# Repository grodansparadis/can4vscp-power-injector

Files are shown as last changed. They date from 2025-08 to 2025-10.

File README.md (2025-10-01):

# Power injector module for CAN4VSCP

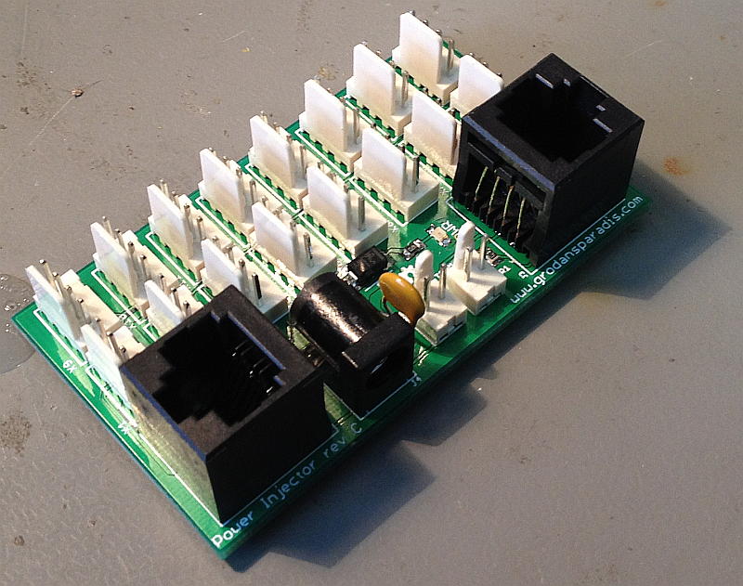
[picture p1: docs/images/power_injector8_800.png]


# Abstract

With the power injector you can power the CAN4VSCP bus and also power up to 16 CAN4VSCP modules using the inter module connector. This is a perfect companion board to use when you need to connect a number of CAN4VSCP boards in a cabinet and then connect them to the world.

It have two 120 ohm terminations that can be activated if needed and two RJ-45 connectors for easy connection.

The module has a resettable fuse that allow a maximum of 500 mA for all modules connected to the board. The fuse will trip at about 800 mA. This can be a good safety precaution for wired networks. 

There is also two smaller versions available.

<hr>

This project is part of the <a href="http://www.vscp.org">VSCP (Very Simple Control Protocol) project</a>. 

<hr>

## Project files

### User manual
  * [User Manual](https://grodansparadis.github.io/can4vscp-power-injector/#)

### Schematic, PCB, 3D files etc
  * [Schematics reversion C](./docs/images/power_injector_rev_c.svg)
 * Hardware design files is made in [KiCad](https://kicad.org) and can be found in the `kicad` directory. Valid from reversion C of the hardware.
   * Gerber files for PCB production can be found in the `gerber` directory (in the `kicad` folder).
 * Eagle schema and board files for reversion A, B and C can be found in the `eagle` directory. They are no longer actively updated.

 ### Firmware

 The firmware is developed in [MPLAB X IDE](https://www.microchip.com/mplab/mplab-x-ide) using the [XC8 compiler](https://www.microchip.com/mplab/compilers).

  * Binary release files is available [here](https://github.com/grodansparadis/can4vscp-beijing/releases)

### MDF - Module Description File(s)
  * [MDF file version: 9 Release date: 2020-05-14](http://www.eurosource.se/beijing_2.xml)
  * [MDF file version: 1.0.0 Release date: 2015-06-15](http://www.eurosource.se/beijing_1.xml)

### Support
If you need support, please open an issue in the [GitHub repository](https://github.com/grodansparadis/can4vscp-beijing/issues).

### Buy a ready made modules
You can buy a ready made module from [Grodans Paradis](http://www.grodansparadis.com).

### Project related links
  * [VSCP project](https://www.vscp.org)
  * [VSCP Documentation site](https://docs.vscp.org/)
  * [VSCP Wiki](https://github.com/grodansparadis/vscp/wiki)

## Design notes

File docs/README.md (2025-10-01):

## Manual for the Power Injector module

**Document version:** ${/var/document-version} - ${/var/creation-time}
[HISTORY](./history.md)

Power Injector  

The power injector module is a part of the CAN4VSCP family of modules. The module is designed to power the CAN4VSCP bus.Three versions of the module exists, a small version that can power the bus and up to 2 CAN4VSCP modules, a medium version that can power the bus and up to 8 CAN4VSCP modules and a big version that can power the bus and up to 16 CAN4VSCP modules. Only the big version is currently active.

**Power Injector big** is a module that can power the CAN4VSCP bus and also power up to 16 CAN4VSCP modules using the inter module connector. This is a perfect companion board to use when you need to connect a number of CAN4VSCP boards in a cabinet and then connect them to the world.

The module can be powered from 7 to 28 VDC and can deliver up to 500 mA on the CAN4VSCP bus. The module has a number of safety features like over current shutdown (800mA) and reverse polarity protection.

* [Repository for the module](https://github.com/grodansparadis/can4vscp-accra)
* This manual is available [here](https://grodansparadis.github.io/can4vscp-power-injector/)
* Latest schema for the module is available [here](./images/power_injector_rev_c.svg)

## VSCP

VSCP logo

VSCP is a free and open automation protocol for IoT and m2m devices. Visit [the VSCP site](https://www.vscp.org) for more information.

**VSCP is free.** Placed in the **public domain**. Free to use. Free to change. Free to do whatever you want to do with it. VSCP is not owned by anyone. VSCP will stay free and gratis forever.

The specification for the VSCP protocol is [here](https://docs.vscp.org) 

VSCP documentation for various parts can be found [here](https://docs.vscp.org/).

If you use VSCP please consider contributing resources or time to the project ([https://github.com/sponsors/grodansparadis](https://github.com/sponsors/grodansparadis)).

## Buy a module

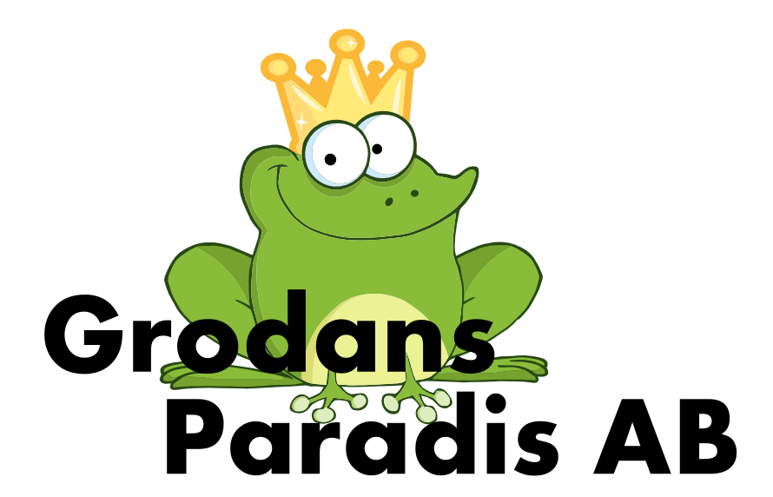
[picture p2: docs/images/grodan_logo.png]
Grodans PAradis AB


Ready made modules can be bought from [Grodans Paradis AB](https://www.grodansparadis.com).

## Document license

This document is licensed under [Creative Commons BY 4.0](https://creativecommons.org/licenses/by/4.0/) and can be freely copied, redistributed, remixed, transformed, built upon as long as you give credits to the author.

[filename](./bottom-copyright.md ':include')

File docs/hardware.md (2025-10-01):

## Most current information

You can find the most current information about the Power Injector module at it's repository <https://github.com/grodansparadis/can4vscp-power-injector> and in the documentation at 
<https://grodansparadis.github.io/can4vscp-power.injector>. In the repository you can
also find links to the latest firmware, drivers and schematics etc for
its use. You can find links to where you can buy ready made modules here.

## The raw facts

| Parameter | Value |
| --- | --- |
| Current hardware reversion | C |
| Supply voltage | \+9 - +28 VDC |
| PCB Size | 42mm x 72mm |

## Schematics



Schematics: Rev C 

## Board components

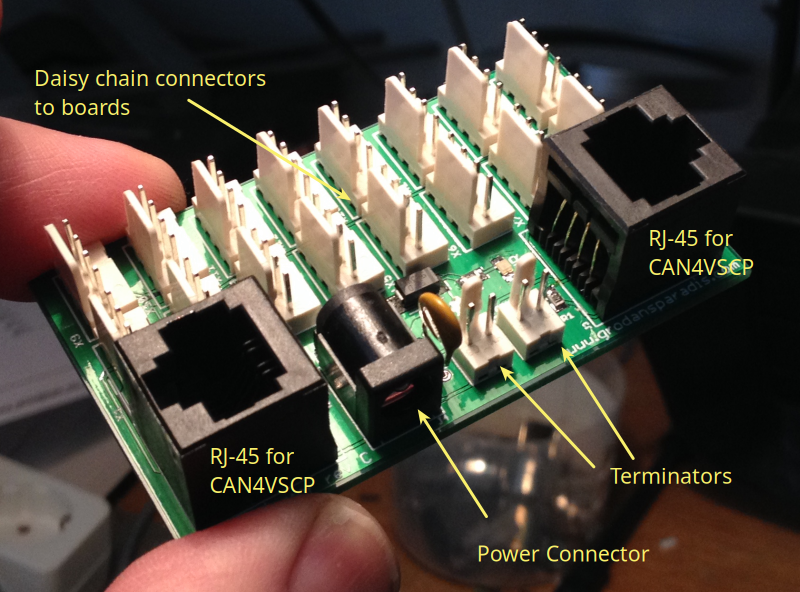
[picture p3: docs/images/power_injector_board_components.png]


## Connectors

### Power jack
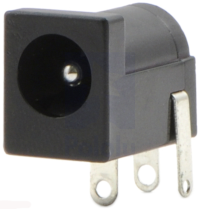
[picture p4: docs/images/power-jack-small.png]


The power connector is a standard 2.1/5.5 mm DC power jack with center pin positive. The voltage range is +9VDC to +28VDC. Maximum current is 500 mA. The power supply should be able to deliver at least 1A to have some margin.

### RJ-XX pin-out

The unit is powered over the CAN4VSCP bus or via the power connector. The CAN4VSCP normally uses CAT5 or better twisted pair cable. You can use other cables if you which. The important thing is that the CANH and CANL signals uses a twisted cable. For connectors you can use RJ10, RJ11, RJ12 or the most common RJ45 connectors.

Recommended connector is RJ-34/RJ-12 or RJ-11 with pin out as in this
table.

| Pin | Use | RJ-11 | RJ-12 | RJ-45 | Patch Cable wire color T568B |
| ----- | --- | ----- | ----- | ----- | --- |
| 1 | \+9-28V DC | | | RJ-45 | Orange/White |
| 2 1 | \+9-28V DC | | RJ-12 | RJ-45 | Orange |
| 3 2 1 | \+9-28V DC | RJ-11 | RJ-12 | RJ-45 | Green/White |
| 4 3 2 | CANH | RJ-11 | RJ-12 | RJ-45 | Blue |
| 5 4 3 | CANL | RJ-11 | RJ-12 | RJ-45 | Blue/White |
| 6 5 4 | GND | RJ-11 | RJ-12 | RJ-45 | Green |
| 7 6 | GND | | RJ-12 | RJ-45 | Brown/White |
| 8 | GND | | | RJ-45 | Brown |

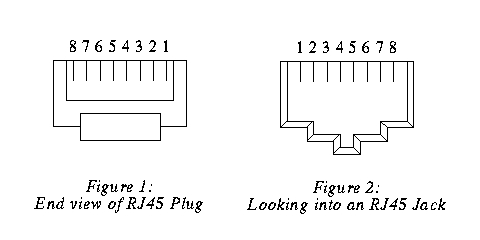
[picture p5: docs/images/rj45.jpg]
RJ-11/12/45 pin-out
 

**RJ-11/12/45 pin-out**

**!** Always use a pair of twisted wires for CANH/CANL for best noise immunity. If the EIA/TIA 56B standard is used this condition will be satisfied. This is good as most Ethernet networks already is wired this way.

### Inter module connector

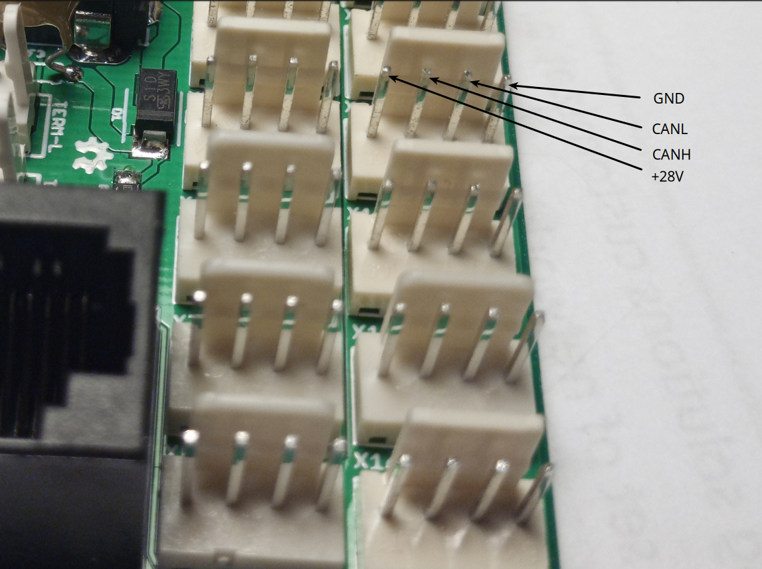
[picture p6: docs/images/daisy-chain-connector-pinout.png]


The inter module connector can be used to connect modules that are physically close to each other together in an easy way. Remember that the minimum length of a connection cable is 30 cm.

| Pin | Description |
| --- | --- |
| 1 | +9V - +28V DC |
| 2 | CANH |
| 3 | CANL |
| 4 | GND |

[filename](./bottom-copyright.md ':include')

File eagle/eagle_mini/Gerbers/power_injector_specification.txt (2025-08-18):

Ake Hedman
Grodans Paradis AB

Date:				2014-06-18
Part Number: 		Power Injector
Number of boards: 	120
Number of layers: 	2 
Material: 			FR4
Final Thickness:	1.6 mm
Final copper:		1/1oz
Surface treatment: 	ENIG
Unit Size:			72 x 20 mm
Panel Size:		
Unit/panel:			12
Solder Mask:		Green
Silk Screen: 		White	
Outline Profile:	CNC Routing + V-cut
X-out Allowed:		1
Stencil needed:		no

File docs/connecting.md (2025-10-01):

# Connecting CAN4VSCP devices

## Cable length

CAN4VSCP always communicate with 125kbps. This means that if you use a good quality cable it can be up to a maximum of 500 meters using AWG24AWG24 or similar (CAT5) . Actual length depend on the environment and other parameters. Drops with a maximum length of 24 meters can be
taken from this cable and the sum of all drops must not exceed a total of 120 meters.

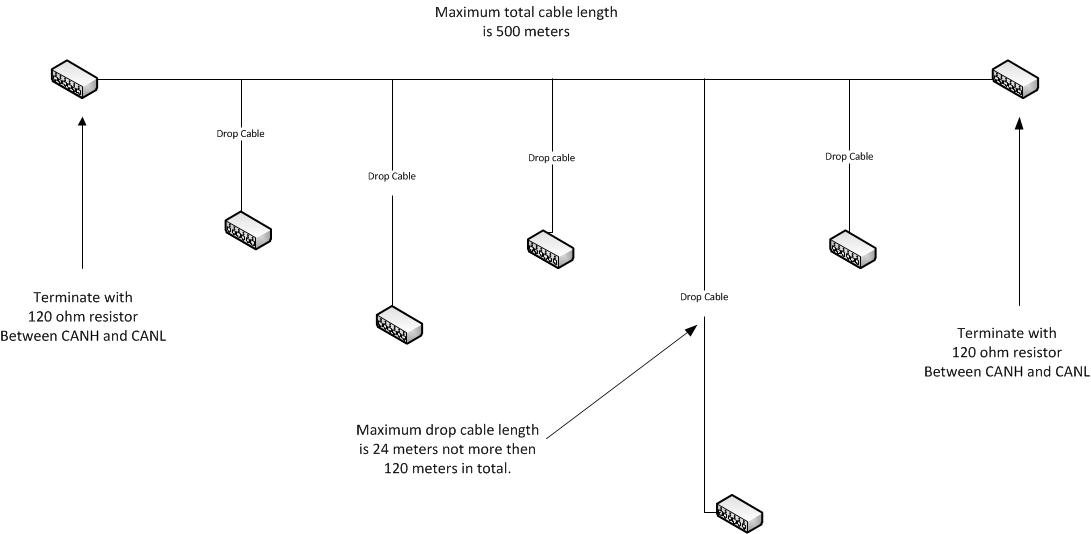
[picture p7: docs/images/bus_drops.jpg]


CAN4VSCP bus with drops and terminations

## Termination

The CAN4VSCP bus, as all CAN based networks, should be terminated with a 120 ohms resistor between CANH and CANL at both ends of the cable.

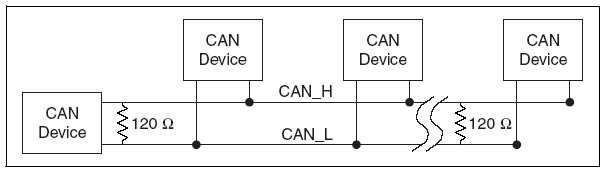
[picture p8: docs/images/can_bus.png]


If you use CAT5 this termination should be placed between the blue - blue/white cables at both end of your bus.

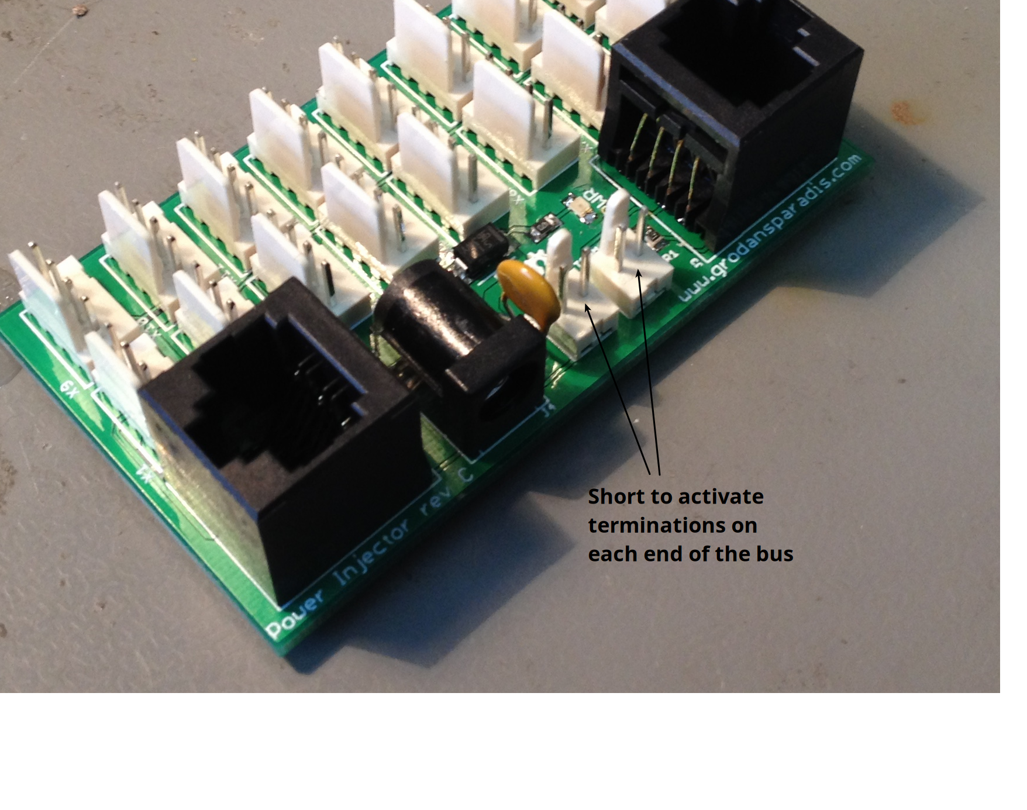
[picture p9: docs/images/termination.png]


On the board there is two connectors that should be shorted to activate the on-board terminations. 

**Why is terminators required?**

Terminators are needed to cancel signal echos in the cable. In short you get less noise in the cable if you use them. It is recommended to use
them even if at 125 kbit it is possible that your bus will work anyway as CAN is pretty forgiving at this transmission speed.

## Power the module

You normally power the module through the power connector (center pin is plus) or through one of the RJ45 connectors over the CAN4VSCP bus. The voltage range is +9VDC - 28VDC.

## Best practice

Even if it is possible to have cable lengths up to 500 meters it is better to stay at shorter distances to have some margins. Here are some
guidelines for a reliable set up

  - Total cable length of 300m, stub cables count double their length in that total.
  - Nodes count as 6m in that total. 
  - Never less than 30cm of cable between nodes nor between a stub connection and a node. 
  - No more than 50 nodes connected.

Following this best practice you will have a setup that will work reliable even in harsh environments.

[filename](./bottom-copyright.md ':include')

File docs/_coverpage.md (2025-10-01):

VSCP logo

# Manual for the Power Injector module

Scroll down to view docs.

[Homepage](https://www.vscp.org)
[Docs](https://www.vscp.org/#documentation)
[Downloads](https://www.vscp.org/#download)
[Get Started](./README)

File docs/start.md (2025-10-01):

# Accra - General counter module

**Document reversion**: 1.0.0 2015-07-07

Copyright © 2000-2025 Åke Hedman, [Grodans Paradis
AB](http://www.grodansparadis.com),
\<[akhe@grodansparadis.com](akhe@grodansparadis.com)\>

Accra

This documentation is for the [Accra
module](http://www.grodansparadis.com/accra/accra.html). The module is
available for international purchase from the
[FrogShop](http://www.frogshop.se).

  - [Introduction](Introduction)
  - [Getting Started](Getting%20Started)
  - [Hardware](Hardware)
  - [CAN4VSCP cabling](CAN4VSCP%20cabling)
  - [Updating the firmware](Replacing%20the%20firmware)
  - [Registers](registers)
  - [Abstractions](Abstractions)
  - [Alarms](Alarms)
  - [Decision Matrix](decisionmatrix)
  - [Events](Events)
  - [Recipes](Recipes)
  - [faq](faq)

//**Disclaimer:** © 2011-2025 Grodans Paradis AB. All rights reserved.
Grodans Paradis AB®, logo and combinations thereof, are registered
trademarks of Grodans Paradis AB. Other terms and product names may be
trademarks of others. The information in this document is provided in
connection with Grodans Paradis AB products. No license, express or
implied or otherwise, to any intellectual property right is granted by
this document or in connection with the sale of Grodans Paradis AB
products. Neither the whole nor any part of the information contained in
or the product described in this document may be adapted or reproduced
in any material from except with the prior written permission of the
copyright holder. The product described in this document is subject to
continuous development and improvements. All particulars of the product
and its use contained in this document are given by Grodans Paradis AB
in good faith. However all warranties implied or expressed including but
not limited to implied warranties of merchantability or fitness for
purpose are excluded. This document is intended only to assist the
reader in the use of the product. Grodans Paradis AB. shall not be
liable for any loss or damage arising from the use of any information in
this document or any error or omission in such information or any
incorrect use of the product. //

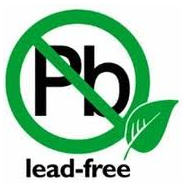
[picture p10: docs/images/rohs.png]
 All boards produced by Grodans Paradis AB are ROHS
compliant.

\----   
<center> **Grodans Paradis AB** Brattbergavägen 17, 827 70 LOS SWEDEN  
**email:** [info@grodansparadis.com](info@grodansparadis.com) **phone:**
+46 (0)8 40011835  
**web:**<https://www.grodansparadis.com>  
</center>

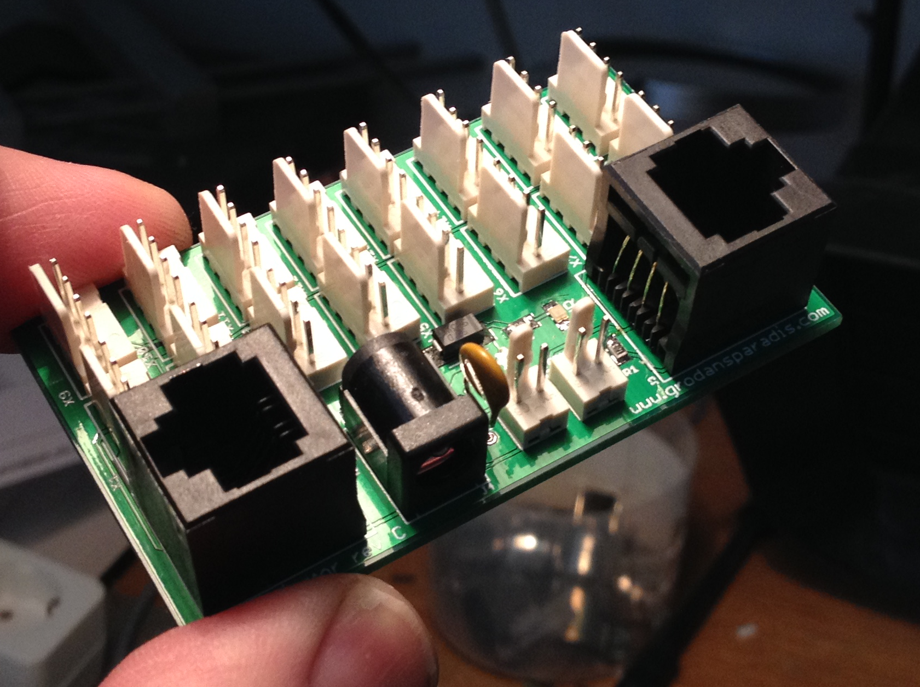
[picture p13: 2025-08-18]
docs/images/power_injector13.png

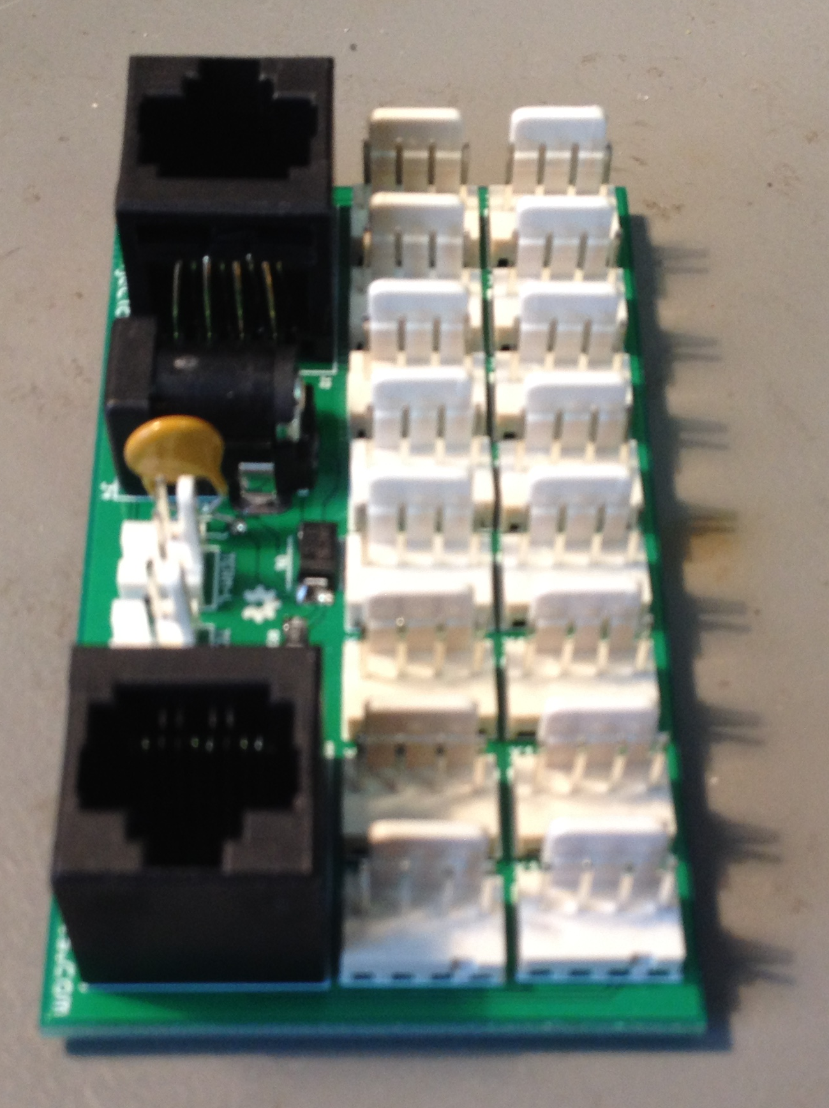
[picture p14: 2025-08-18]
docs/images/power_injector3.png

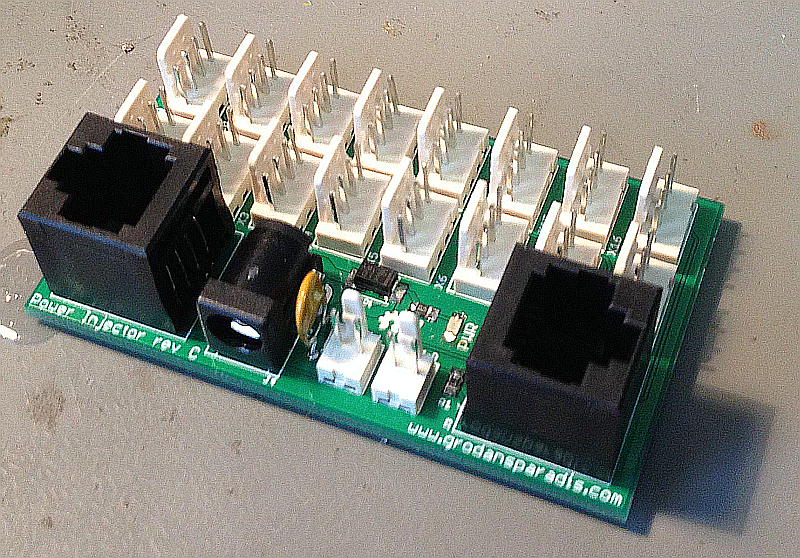
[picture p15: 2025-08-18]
docs/images/power_injector5_800.png

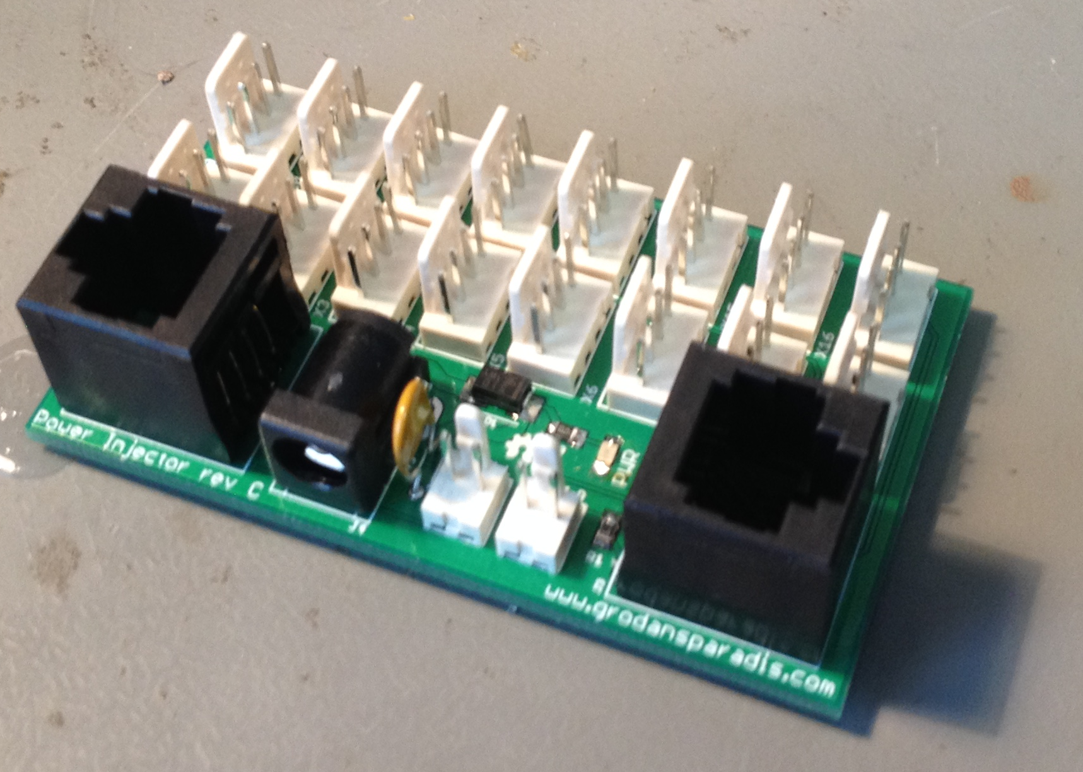
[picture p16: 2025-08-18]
docs/images/power_injector7.png

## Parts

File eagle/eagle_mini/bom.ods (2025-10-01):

Partl | ist exported fro | m C:/Users/akhe/Do | cuments/dev | elopment/hardware_zeus/can | 4vscp/power_inje | ctor/eagle/power_injector_r | ev_a.sch at 2011-10-03 | 11:50:20
Part | Value | Device Pa | ckage | Description | Description | Supplier Partnumber | Price
D1 | PMEG3015EH,115 | DIODE-SMB SM | B | DIODE | Protection diod | Digikey 568-4127-1-ND | 3,84
F1 | MF-R050 | R-EU_M0805 M0 | 805 | RESISTOR, European symbol | Fuse | Digikey MF-r050-nd | 6,24
F2 | MF-R050 | R-EU_M0805 M0 | 805 | RESISTOR, European symbol | Fuse | Digikey MF-r050-nd | 6,24
F3 | MF-R050 | R-EU_M0805 M0 | 805 | RESISTOR, European symbol | Fuse | Digikey MF-r050-nd | 6,24
J1 |  | JACK-PLUG0 SP | C4077 | DC POWER JACK | Power connector | Digikey CP-102A-ND | 7,36
J2 | A00-108-220-450 | A00-108-220-450 RJ | -45 |  | RJ-45 connector | Digikey 151-1099-nd | 5,6
J3 | A00-108-220-450 | A00-108-220-450 RJ | -45 |  | RJ-45 connector | Digikey 151-1099-nd | 5,6
LED1 |  | LEDCHIP-LED0805 CH | IP-LED0805 | LED | Green LED | Digikey 475-1410-1-nd | 0,88
LED2 |  | LEDCHIP-LED0805 CH | IP-LED0805 | LED | Green LED | Digikey 475-1410-1-nd | 0,88
LED3 |  | LEDCHIP-LED0805 CH | IP-LED0805 | LED | Green LED | Digikey 475-1410-1-nd | 0,88
LED4 |  | LEDCHIP-LED0805 CH | IP-LED0805 | LED | Green LED | Digikey 475-1410-1-nd | 0,88
R1 | 4k7 | R-EU_R0805 R0 | 805 | RESISTOR, European symbol | Resistor | Bejoken 454668 | 0,01
R2 | 4k7 | R-EU_R0805 R0 | 805 | RESISTOR, European symbol | Resistor | Bejoken 454668 | 0,01
R3 | 4k7 | R-EU_R0805 R0 | 805 | RESISTOR, European symbol | Resistor | Bejoken 454668 | 0,01
R4 | 4k7 | R-EU_R0805 R0 | 805 | RESISTOR, European symbol | Resistor | Bejoken 454668 | 0,01
 |  |  |  |  |  |  | 44,68

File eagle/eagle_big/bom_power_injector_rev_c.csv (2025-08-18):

Part | Value | Device | Package | Description | MF | MPN | OC_FARNELL | OC_NEWARK
D1 | PMEG3015EH,115 | DIODE-SMB | SMB | DIODE
F3 | MF-R050 | R-EU_0204/5 | 0204/5 | RESISTOR, European symbol
J2 | A00-108-220-450 | A00-108-220-450 | RJ-45
J3 | A00-108-220-450 | A00-108-220-450 | RJ-45
J4 |  | JACK-PLUG0 | SPC4077 | DC POWER JACK |  |  | unknown | unknown
LED1 |  | LEDCHIP-LED0805 | CHIP-LED0805 | LED
R1 | 120 | R-EU_R0805 | R0805 | RESISTOR, European symbol
R2 | 120 | R-EU_R0805 | R0805 | RESISTOR, European symbol
R3 | 4k7 | R-EU_R0805 | R0805 | RESISTOR, European symbol
TERM-L | 22-23-2021 | 22-23-2021 | 22-23-2021 | .100 (2.54mm) Center Header - 2 Pin" | MOLEX | 22-23-2021 | 1462926 | 25C3832
TERM-R | 22-23-2021 | 22-23-2021 | 22-23-2021 | .100 (2.54mm) Center Header - 2 Pin" | MOLEX | 22-23-2021 | 1462926 | 25C3832
X1 | 22-23-2041 | 22-23-2041 | 22-23-2041 | .100 (2.54mm) Center Header - 4 Pin" | MOLEX | 22-23-2041 | 1462920 | 38C0355
X2 | 22-23-2041 | 22-23-2041 | 22-23-2041 | .100 (2.54mm) Center Header - 4 Pin" | MOLEX | 22-23-2041 | 1462920 | 38C0355
X3 | 22-23-2041 | 22-23-2041 | 22-23-2041 | .100 (2.54mm) Center Header - 4 Pin" | MOLEX | 22-23-2041 | 1462920 | 38C0355
X4 | 22-23-2041 | 22-23-2041 | 22-23-2041 | .100 (2.54mm) Center Header - 4 Pin" | MOLEX | 22-23-2041 | 1462920 | 38C0355
X5 | 22-23-2041 | 22-23-2041 | 22-23-2041 | .100 (2.54mm) Center Header - 4 Pin" | MOLEX | 22-23-2041 | 1462920 | 38C0355
X6 | 22-23-2041 | 22-23-2041 | 22-23-2041 | .100 (2.54mm) Center Header - 4 Pin" | MOLEX | 22-23-2041 | 1462920 | 38C0355
X7 | 22-23-2041 | 22-23-2041 | 22-23-2041 | .100 (2.54mm) Center Header - 4 Pin" | MOLEX | 22-23-2041 | 1462920 | 38C0355
X8 | 22-23-2041 | 22-23-2041 | 22-23-2041 | .100 (2.54mm) Center Header - 4 Pin" | MOLEX | 22-23-2041 | 1462920 | 38C0355
X9 | 22-23-2041 | 22-23-2041 | 22-23-2041 | .100 (2.54mm) Center Header - 4 Pin" | MOLEX | 22-23-2041 | 1462920 | 38C0355
X10 | 22-23-2041 | 22-23-2041 | 22-23-2041 | .100 (2.54mm) Center Header - 4 Pin" | MOLEX | 22-23-2041 | 1462920 | 38C0355
X11 | 22-23-2041 | 22-23-2041 | 22-23-2041 | .100 (2.54mm) Center Header - 4 Pin" | MOLEX | 22-23-2041 | 1462920 | 38C0355
X12 | 22-23-2041 | 22-23-2041 | 22-23-2041 | .100 (2.54mm) Center Header - 4 Pin" | MOLEX | 22-23-2041 | 1462920 | 38C0355
X13 | 22-23-2041 | 22-23-2041 | 22-23-2041 | .100 (2.54mm) Center Header - 4 Pin" | MOLEX | 22-23-2041 | 1462920 | 38C0355
X14 | 22-23-2041 | 22-23-2041 | 22-23-2041 | .100 (2.54mm) Center Header - 4 Pin" | MOLEX | 22-23-2041 | 1462920 | 38C0355
X15 | 22-23-2041 | 22-23-2041 | 22-23-2041 | .100 (2.54mm) Center Header - 4 Pin" | MOLEX | 22-23-2041 | 1462920 | 38C0355
X16 | 22-23-2041 | 22-23-2041 | 22-23-2041 | .100 (2.54mm) Center Header - 4 Pin" | MOLEX | 22-23-2041 | 1462920 | 38C0355

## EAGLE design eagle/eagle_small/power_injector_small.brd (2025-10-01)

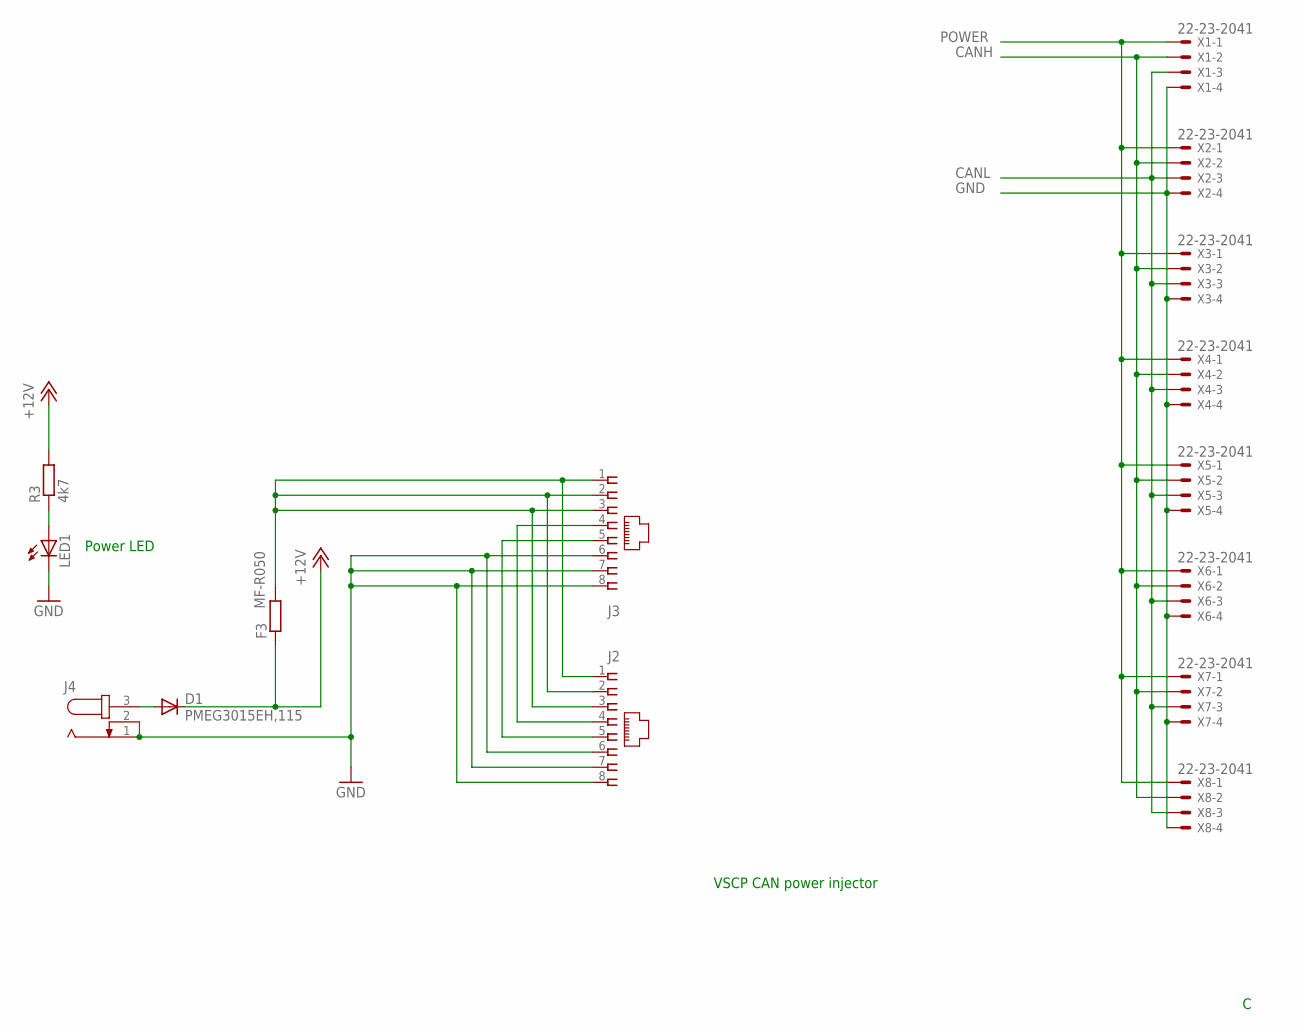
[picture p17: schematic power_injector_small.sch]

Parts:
D1: PMEG3015EH,115; SMB
F3: MF-R050; 0204/5
J2, J3: A00-108-220-450; RJ-45
J4: JACK-PLUG0; SPC4077
LED1: LEDCHIP-LED0805; CHIP-LED0805
R3: 4k7; R0805
X1, X2, X3, X4, X5, X6, X7, X8: 22-23-2041

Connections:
+12V: D1.C, F3.1, R3.2
CANH: J2.4, J3.4, X1.2, X2.2, X3.2, X4.2, X5.2, X6.2, X7.2, X8.2
CANL: J2.5, J3.5, X1.3, X2.3, X3.3, X4.3, X5.3, X6.3, X7.3, X8.3
GND: J2.6, J2.7, J2.8, J3.6, J3.7, J3.8, J4.1, J4.2, LED1.C, X1.4, X2.4, X3.4, X4.4, X5.4, X6.4, X7.4, X8.4
unnamed: LED1.A, R3.1
unnamed: D1.A, J4.3
POWER: F3.2, J2.1, J2.2, J2.3, J3.1, J3.2, J3.3, X1.1, X2.1, X3.1, X4.1, X5.1, X6.1, X7.1, X8.1

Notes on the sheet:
Power LED
VSCP CAN power injector

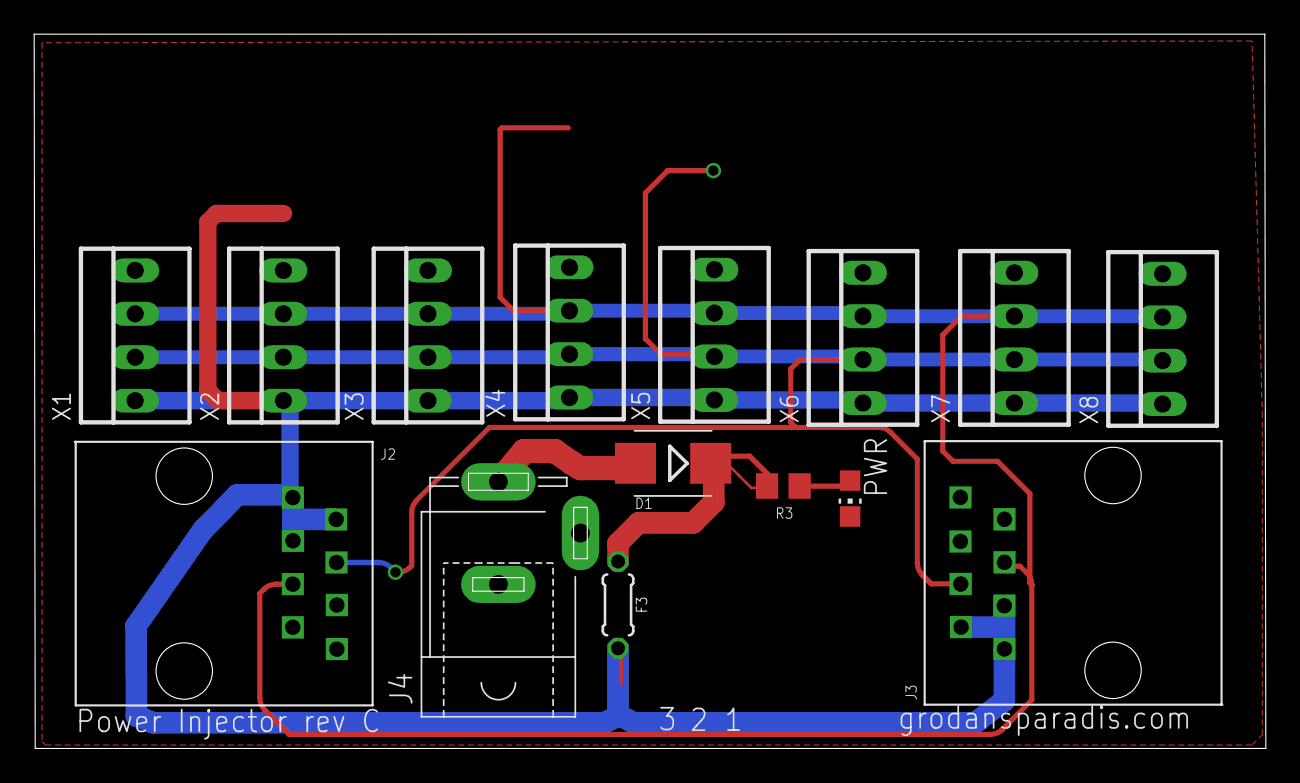
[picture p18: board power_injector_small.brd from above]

Board: 2 copper layers, 72.1 x 41.8 mm, 15 parts (0 on the bottom side), 7 nets.

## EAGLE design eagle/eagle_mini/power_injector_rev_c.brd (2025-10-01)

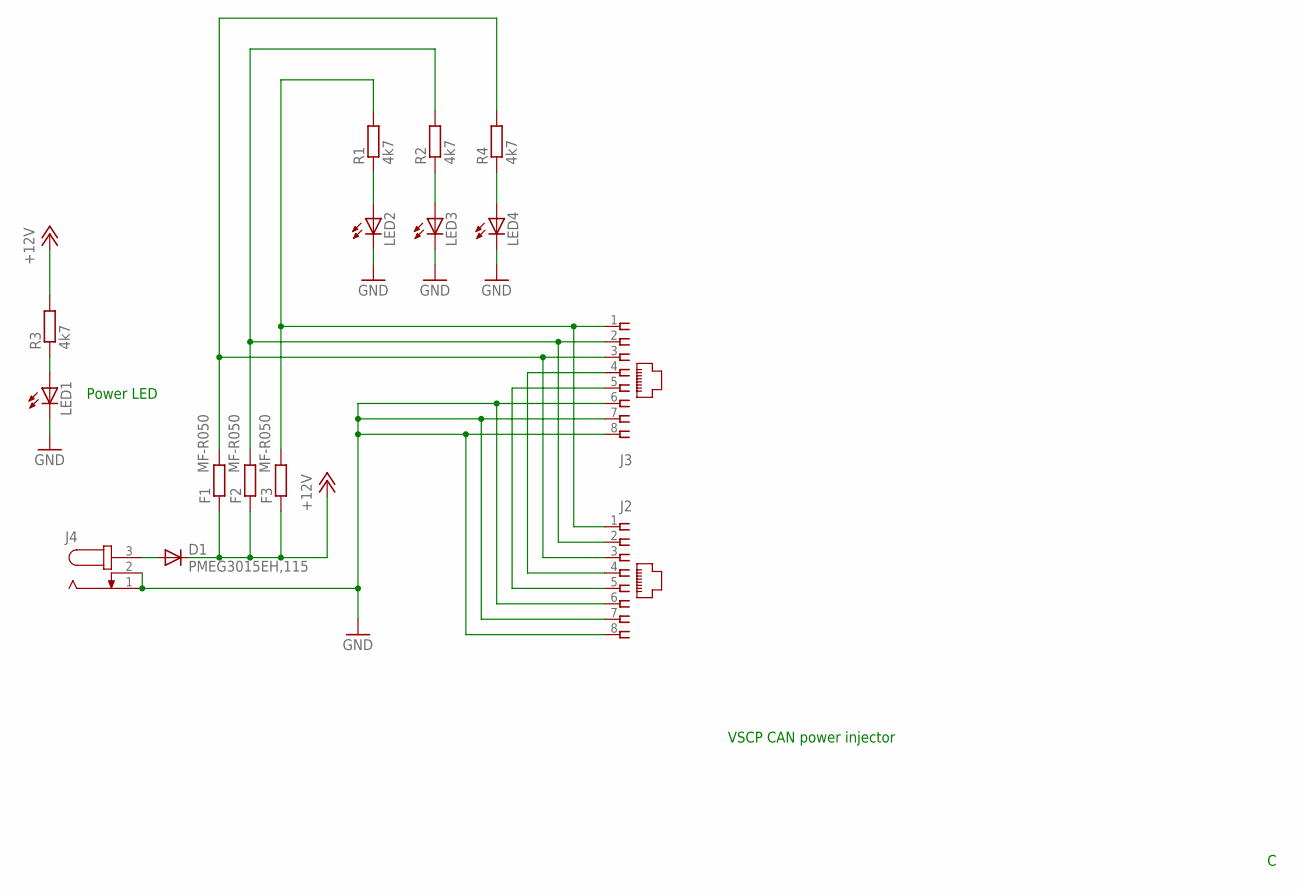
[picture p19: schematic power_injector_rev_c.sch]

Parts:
D1: PMEG3015EH,115; SMB
F1, F2, F3: MF-R050; 0204/5
J2, J3: A00-108-220-450; RJ-45
J4: JACK-PLUG0; SPC4077
LED1, LED2, LED3, LED4: LEDCHIP-LED0805; CHIP-LED0805
R1, R2, R3, R4: 4k7; R0805

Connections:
+12V: D1.C, F1.1, F2.1, F3.1, R3.2
GND: J2.6, J2.7, J2.8, J3.6, J3.7, J3.8, J4.1, J4.2, LED1.C, LED2.C, LED3.C, LED4.C
unnamed: LED3.A, R2.1
unnamed: LED1.A, R3.1
unnamed: J2.4, J3.4
unnamed: J2.5, J3.5
unnamed: LED4.A, R4.1
unnamed: LED2.A, R1.1
unnamed: D1.A, J4.3
PWR1: F3.2, J2.1, J3.1, R1.2
PWR2: F2.2, J2.2, J3.2, R2.2
PWR3: F1.2, J2.3, J3.3, R4.2

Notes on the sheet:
Power LED
VSCP CAN power injector

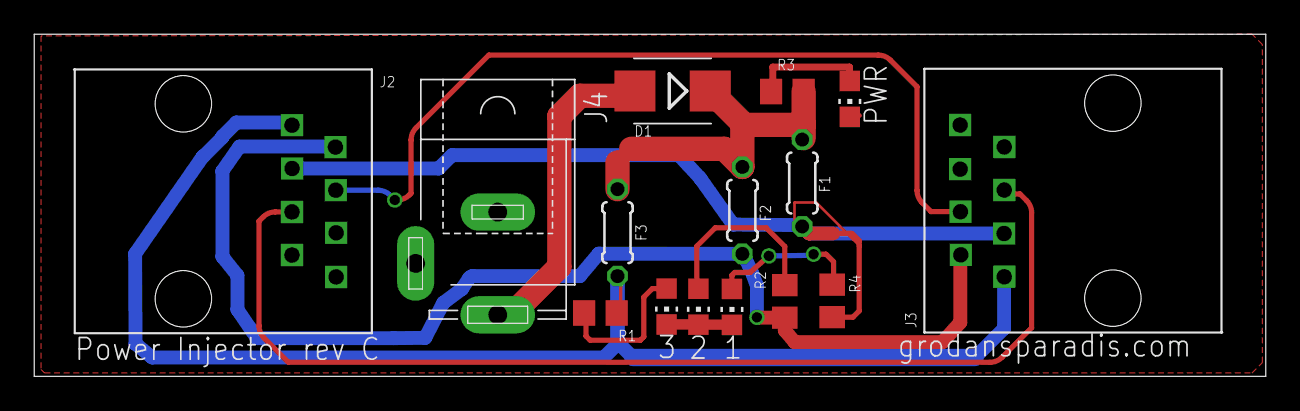
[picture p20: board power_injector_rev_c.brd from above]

Board: 2 copper layers, 72.0 x 20.0 mm, 15 parts (0 on the bottom side), 12 nets.

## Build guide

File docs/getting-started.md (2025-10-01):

You need

  * RJ-45 patch cables or similar.
  * A stable +9V - +28V DC power source.
  * Some CAN4VSCP modules to connect to the bus.

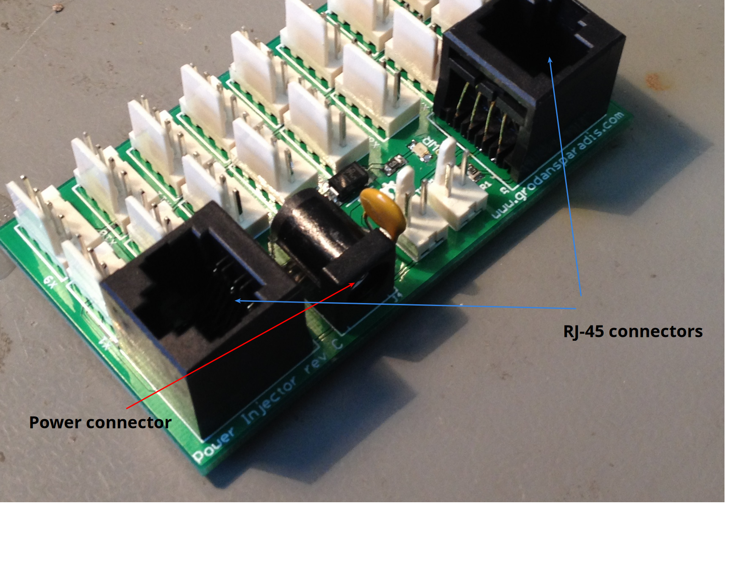
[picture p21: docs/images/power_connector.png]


The Power Injector module is powered from either a power connector (center pin is plus) or from  CAN4VSCP bus on one (**only one**) of the RJ-45 connectors. Think of the RJ-45 connectors as they are sitting on each end of a bus and that the terminations are on the same end as the power injector. 

[This article](https://github.com/grodansparadis/vscp/wiki/Connecting-CAN4VSCP-devices-together) have information on how the bus is powered and set up. Follow it for a reliable setup. Don't forget the 120 ohm terminators at each end of the bus. <span class="underline">They are important\!</span> 

When you power the module by inserting the RJ-45 cable the red LED on the board should light up to indicate it is powered. This is just a
power indicator LED. When you power the board for the first time the
green led starts to blink to indicate that the module search for a
nickname. During normal operation this LED should light steady.

Remember that there need to be <span class="underline">at least
two</span> CAN4VSCP (or other CAN device set to 125kbps) devices (one
additional) if you have the [Frankfurt
RS-232](https://github.com/grodansparadis/can4vscp-frankfurt-rs232)
or some other bus interface. A single device can't talk by
itself on a bus. It's an error.

[filename](./bottom-copyright.md ':include')

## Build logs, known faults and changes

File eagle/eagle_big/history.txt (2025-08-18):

History file for big power injector
===================================

2015-12-22 AKHE - Named D1
2015-09-28 AKHE - Added terminators.
2015-09-28 AKHE - CAN/CANH now goes through connectors in sequence.

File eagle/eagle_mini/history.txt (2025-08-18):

CAN4VSCP Power injector
=======================

2015-08-26 - AKHE - tidied up
2014-06-14 - AKHE - Changed input diod to PMEG3015EH,115 - http://www.digikey.com/product-detail/en/PMEG3015EH,115/568-4127-1-ND/1589942
2014-11-24 - AKHE - Wring wiring between RJ45's fixed.
2014-11-24 - AKHE - Rev C
2014-06-18 - AKHE - Fixing dimensions
2014-06-18 - AKHE - Job sent out
2012-01-20 - AKHE - Changed power connector with one with 1.1mm holes.
2012-01-20 - AKHE - Rev B Wrong footprint for F1, F2, F3 corrected.
2012-01-20 - AKHE - Rev B

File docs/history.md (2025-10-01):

# Change Log for Accra

Change log for the module is at
[here](https://github.com/grodansparadis/can4vscp-accra/blob/master/HISTORY.txt)

| Date | By | Description |
| ---- | -- | ---  |
| 250113 | akhe | Fixed some links |
| 220602 | akhe | Transferred to Markdown format |

[filename](./bottom-copyright.md ':include')

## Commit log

2025-08-18 Convert schema to kicad
    [bom_power_injector_rev_c.csv, power_injector_rev_b.brd, power_injector_rev_c.kicad_pcb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]
2025-10-01 Rearranged files (in a more logical way)
    [bom.ods, bom_power_injector_rev_c.csv, power_injector_rev_a.brd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]
2025-10-01 Added descriptions of connectors
2025-10-01 Added power jack picture
2026-05-05 Added screw terminal version
    [power_injector_rev_c-B_Cu.gbr, power_injector_rev_c-B_Mask.gbr, power_injector_rev_c-B_Paste.gbr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]
2026-08-19 Named LEDS and termination on silcscreen
    [power_injector_rev_c.kicad_pcb]
